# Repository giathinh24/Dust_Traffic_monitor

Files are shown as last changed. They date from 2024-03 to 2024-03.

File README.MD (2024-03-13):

# Development manual

## Arduino_code directory
The file in this directory is coded in Arduino programming language, but is compiled and loaded to an ARM-based STM32 BluePill development board.
Product link: *https://hshop.vn/products/kit-ra-chon-stm32f103c8t6*

In order to achive this, the developer must first install the **STM32F1 boards (Arduino-STM32)** board manager. Then, inside Arduino IDE, the developer must change the board from **Arduino** to the correct STM32 board (For Blue Pill development board, its STM32F103C8T6). This will allow the user to program the STM32 board with ease by utilizing Arduino high-level features, instead of having to code in bare C.

To add STM32F1 board manager:
-Open File > Preference
-Paste this link into your *Additional Boards Manager URLs*: http://dan.drown.org/stm32duino/package_STM32duino_index.json
-Click OK
-Go to Tools > Board > Board manager
-Install *STM32F1xx/GD32F1xx board* package

Now you have STM32F1xx boards manager. To use, go to Tools > Board > STM32F1 boards > Select the right model (Likely the *Fake STM32F103C8* one)

Now you can compile Arduino code into STM32 bytecode. But to upload, you cannot use USB cable like an Arduino, but you have to buy an ST-Link device. Product link: https://hshop.vn/products/mach-nap-st-link-v2

Now you can code, compile, and upload to an STM32 board, congrats.

## RaspberryPi_code directory
This directory hold the Python code to run on Raspbery Pi device.

The main file is **Run.py** where all the code are.
**Set_wifi.py** automatically write a .conf file that can connect the device to a new Wifi network. The user will be prompted with the SSID and password. Once completed, restart the device, the new Wifi connection will take effect. Be careful that this will log the device out of the old network, so if you rely on SSH to connect to the Raspberry Pi device, this operation will log you out.
**Set_parameters.py** is used to set 5 parameters that are used by the Run.py script. These are:
-video_cut_interval: How long should each video be cut before sending to the cloud (unit in seconds)
-frame_rate: Frame rate of the video. Maximum 30. Recommended 10. Higher FPS means larger files (unit in FPS)
-node_name: Name of the current device. Used to reference the device on cloud data base.
-data_buffer_time: How long should the dust data (csv files) be kept on the internal storage before clean up (unit in days)
-video_buffer_time: How many videos can buffer before clean up. The Run script will take time to upload a video to the cloud, so a video has to be buffered until the upload operation is done, before we can delete it. But the internal device storage is limited, so we cannot buffer too much. This param set how many files can exist in the buffer storage. Chosing 5 will means the device will only buffer the most recent 5 videos, once a new video is added, the oldest one will be deleted to make room. Please make this choice base on how big is the device's internal storage.

## PCB directory
**DustSensorMk1.sch** is the schematic file describe the logical connection between components
**DustSensorMk1.brd** is the board file describe the physical layout of the PCB

**CAMOutputs** directory store the CAM files that are used for PCB miling machines.
For machines used at VGU, use files in the GerberFiles directory.

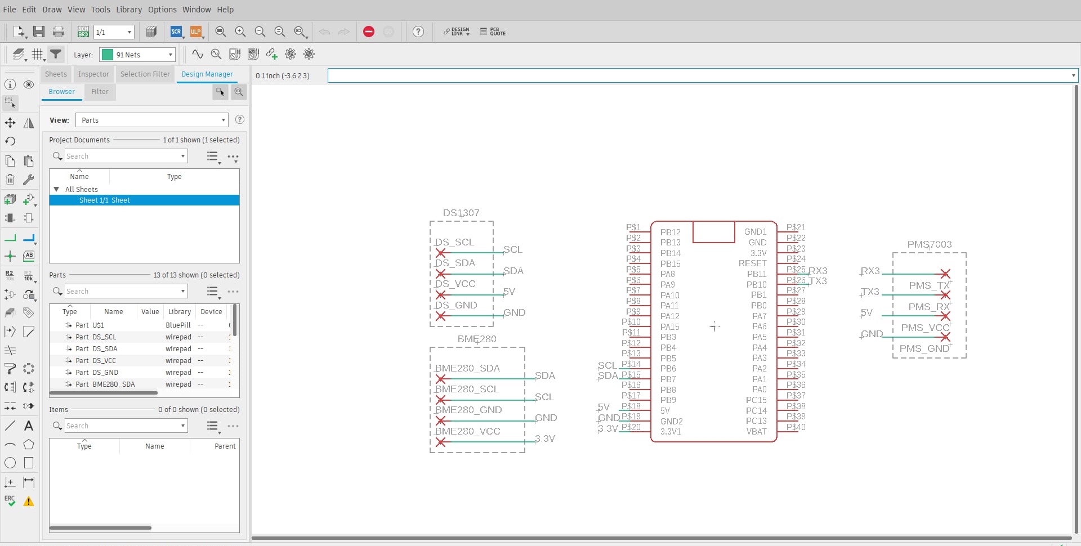
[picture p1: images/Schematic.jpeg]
Schematic

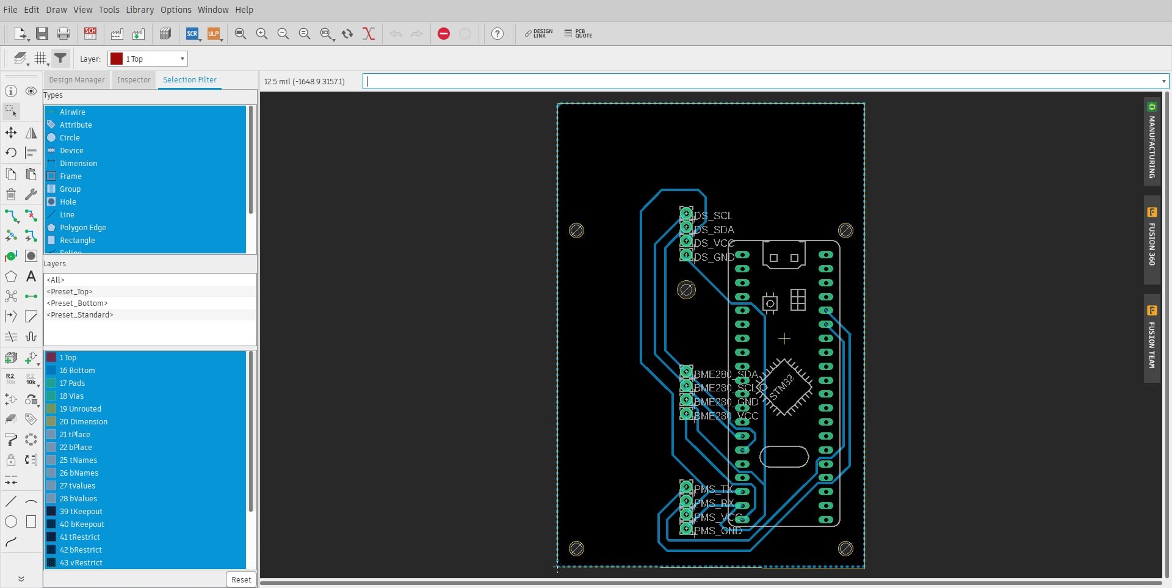
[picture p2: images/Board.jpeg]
Board layout


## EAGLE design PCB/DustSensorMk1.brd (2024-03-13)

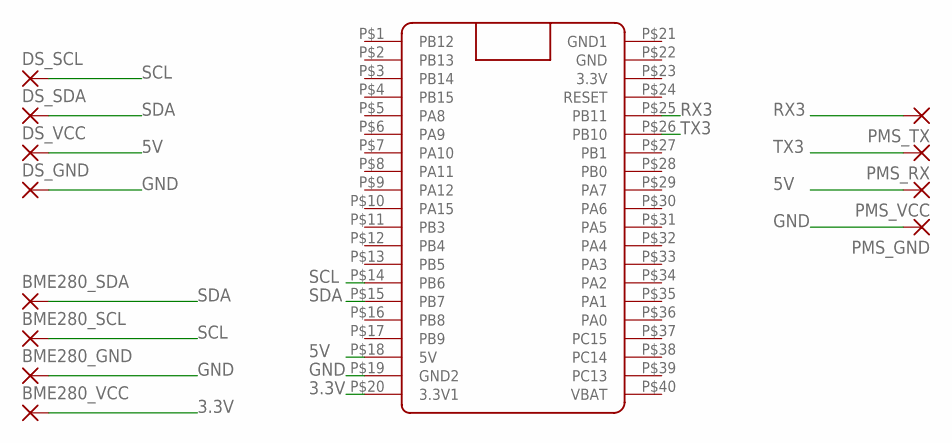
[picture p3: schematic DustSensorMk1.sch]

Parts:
BME280_GND, BME280_SCL, BME280_SDA, BME280_VCC: 2,15/1,0
DS_GND: 2,15/1,0
DS_SCL: 2,15/1,0
DS_SDA: 2,15/1,0
DS_VCC: 2,15/1,0
PMS_GND: 2,15/1,0
PMS_RX: 2,15/1,0
PMS_TX: 2,15/1,0
PMS_VCC: 2,15/1,0
U$1: BLUE_PILL

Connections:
3.3V: BME280_VCC.1, U$1.P$20 (3.3V1)
5V: DS_VCC.1, PMS_VCC.1, U$1.P$18 (5V)
GND: BME280_GND.1, DS_GND.1, PMS_GND.1, U$1.P$19 (GND2)
GND1: U$1.P$21 (GND1)
RX3: PMS_TX.1, U$1.P$25 (PB11)
SCL: BME280_SCL.1, DS_SCL.1, U$1.P$14 (PB6)
SDA: BME280_SDA.1, DS_SDA.1, U$1.P$15 (PB7)
TX3: PMS_RX.1, U$1.P$26 (PB10)

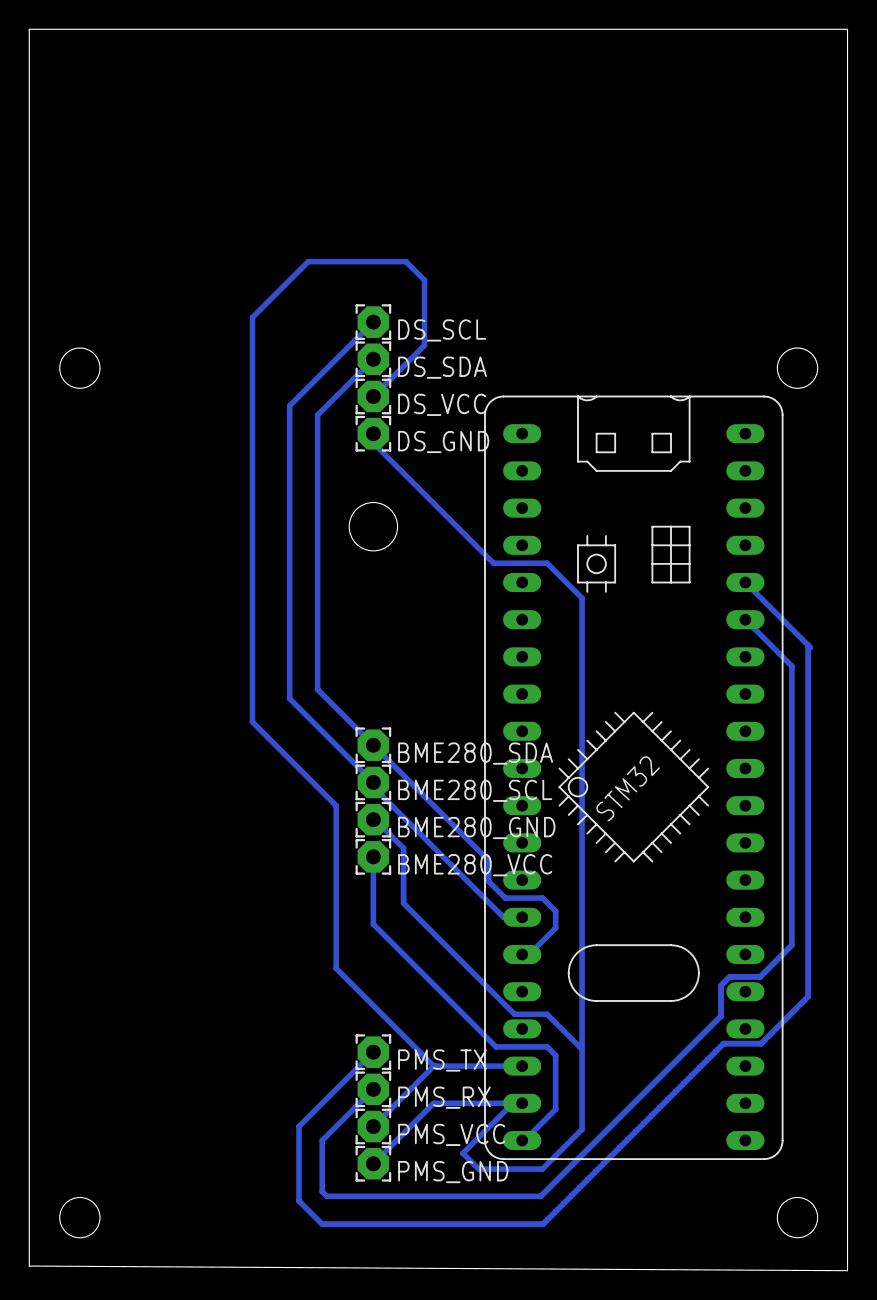
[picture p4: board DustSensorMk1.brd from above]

Board: 2 copper layers, 55.9 x 84.8 mm, 13 parts (0 on the bottom side), 7 nets.

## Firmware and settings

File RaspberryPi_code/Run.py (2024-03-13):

import serial, csv, datetime, time, math, os, sys, glob
from picamera import PiCamera
from azure.storage.blob import BlobServiceClient
from multiprocessing import Process
import RPi.GPIO as GPIO

# Getting parameters from parameters.txt
with open('parameters.txt', 'r') as file:
    lines = file.readlines()
    for line in lines:
        if (len(line)) == 0:
            lines.pop(line)
    video_cut_interval = int(lines[0].strip()) #seconds
    frame_rate = int(lines[1].strip()) #fps
    node_name = lines[2].strip()
    data_buffer_time = int(lines[3].strip()) #the days the datafiles will be kept on local storage
    video_buffer_time = int(lines[4].strip()) #the number of videos stored in the buffer before getting deleted

def upload_blob(container_name, file_path):
    try:
        connect_str = 'place_holder'
        blob_service_client = BlobServiceClient.from_connection_string(connect_str)

        # Create a container
        container_name = container_name
        local_file_name = file_path.split('/')[-1]
        upload_file_path = file_path
	try:
		blob_service_client.create_container(container_name)
	except:
		pass

        # Create a blob client using the local file name as the name for the blob
        blob_client = blob_service_client.get_blob_client(container=container_name, blob=local_file_name)

        print(datetime.datetime.now(), "Uploading to Azure Storage as blob:\t" + local_file_name)

        # Upload the created file
        with open(upload_file_path, "rb") as data:
            blob_client.upload_blob(data)
        print(datetime.datetime.now(), 'Finished uploading')

    except Exception as ex:
        print('Exception:')
        print(ex)

def serial_ports():
    """ Lists serial port names

        :raises EnvironmentError:
            On unsupported or unknown platforms
        :returns:
            A list of the serial ports available on the system
    """
    if sys.platform.startswith('win'):
        ports = ['COM%s' % (i + 1) for i in range(256)]
    elif sys.platform.startswith('linux') or sys.platform.startswith('cygwin'):
        # this excludes your current terminal "/dev/tty"
        ports = glob.glob('/dev/tty[A-Za-z]*')
    elif sys.platform.startswith('darwin'):
        ports = glob.glob('/dev/tty.*')
    else:
        raise EnvironmentError('Unsupported platform')

    result = []
    for port in ports:
        try:
            s = serial.Serial(port)
            s.close()
            result.append(port)
        except (OSError, serial.SerialException):
            pass
    return result

def delete_file(filepath):
    os.remove(filepath)
    print('Deleted', filepath)
    

ports = []
last_ports = []
GPIO.setmode(GPIO.BCM)
GPIO.setup(17, GPIO.OUT)
while True:
    ports = serial_ports()
    if len(last_ports) == 0:
        last_ports = serial_ports()
    com_port = list(set(ports).symmetric_difference(set(last_ports)))
    GPIO.output(17, GPIO.HIGH)
    if len(com_port) > 0:
        GPIO.output(17, GPIO.LOW)
        GPIO.cleanup()
        break
    print(ports, com_port)
    last_ports = ports

run_once = False
camera = PiCamera(framerate=frame_rate, sensor_mode = 5)

ser = serial.Serial(
    port=com_port[0],\
    baudrate=9600,\
    parity=serial.PARITY_NONE,\
    stopbits=serial.STOPBITS_ONE,\
    bytesize=serial.EIGHTBITS,\
        timeout=0)

print("connected to: " + ser.portstr)

epoch_time = int(round(time.time()))+25200
folder_name = '/home/pi/Raw_data'

# Create the raw data folder
try:
    os.mkdir(folder_name)
except:
    print('Folder', folder_name, 'is already created')

while True:
    epoch_time = int(round(time.time()))+25200 #offset for GMT+7
    video_filename = '{}_{}'.format(node_name, datetime.datetime.fromtimestamp(int(epoch_time-25200)).strftime( "%d%m%y_%H%M%S"))
    
    # Upload data file and delete old data file at the end of a day
    if (epoch_time)%86400==0:
        t = Process(target = upload_blob, args = ('node-'+node_name, data_filename,))
        t.start()
        t.join()
        temp_data_filename = '{}_{}'.format(node_name, datetime.datetime.fromtimestamp(int(math.floor((epoch_time-86400*data_buffer_time)/86400)*86400-25200)).strftime("%d%m%y"))+'.csv'
        delete_file_path = folder_name + '/' + temp_data_filename
        if os.path.isfile(delete_file_path):
            t = Process(target = delete_file, args = (delete_file_path,))
            t.start()
            t.join()
        files = os.listdir(folder_name)
        for file in files:
            if os.path.getctime(folder_name+'/'+file) <= int(math.floor((epoch_time-86400*data_buffer_time)/86400)*86400-25200) and file[-4:] == '.csv':
                t = Process(target = delete_file, args = (folder_name+'/'+file,))
                t.start()
                t.join()
    elif math.floor(epoch_time%video_cut_interval) != 0.0:
        data_filename = folder_name + '/{}_{}'.format(node_name, datetime.datetime.fromtimestamp(int(math.floor(epoch_time/86400)*86400-25200)).strftime("%d%m%y"))+'.csv'
    
    if math.floor(epoch_time%video_cut_interval) == 0.0 and not run_once:
        # Cute video
        try:
            camera.stop_recording()
        except:
            pass
        camera.start_recording(folder_name + '/{}.h264'.format(video_filename))
        
        # Upload to cloud storage
        run_once = True
        try:
            temp_video_filename = '{}_{}'.format(node_name, datetime.datetime.fromtimestamp(int((epoch_time-video_cut_interval*2)-25200)).strftime( "%d%m%y_%H%M%S"))+'.h264'
            path_arg = folder_name + '/' + temp_video_filename
            t = Process(target = upload_blob, args = ('node-'+node_name, path_arg,))
            t.start()
            t.join()
        except:
            pass
        
        #Remove old file
        temp_video_filename = '{}_{}'.format(node_name, datetime.datetime.fromtimestamp(int((epoch_time-video_cut_interval*video_buffer_time)-25200)).strftime( "%d%m%y_%H%M%S"))+'.h264'
        delete_file_path = folder_name + '/' + temp_video_filename
        if os.path.isfile(delete_file_path):
            t = Process(target = delete_file, args = (delete_file_path,))
            t.start()
            t.join()
        files = os.listdir(folder_name)
        for file in files:
            if os.path.getctime(folder_name+'/'+file) <= int((epoch_time-video_cut_interval*video_buffer_time)-25200) and file[-5:] == '.h264':
                t = Process(target = delete_file, args = (folder_name+'/'+file,))
                t.start()
                t.join()
    elif math.floor(epoch_time%video_cut_interval) != 0.0:
        run_once = False
    
    # Read data from serial
    line = ser.readline()
    
    # Create new datefile if file not exist
    try:
        with open(data_filename, 'r', newline = ''):
            pass
    except:
        with open(data_filename, 'w', newline = ''):
            pass
    
    # Read serial data and save to log file
    if len(line) > 0:
        data = line.decode('UTF-8').rstrip().split(',')
        data[0] = datetime.datetime.fromtimestamp(int(data[0])).strftime( "%Y-%m-%d %H:%M:%S") 
        print(data)
        with open(data_filename, 'a', newline = '') as file:
            writer = csv.writer(file)
            writer.writerow(data)

ser.close()

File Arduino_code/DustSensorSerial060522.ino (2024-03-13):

#include <BME280I2C.h>
#include <RtcDS1307.h>
#include <Wire.h>

// Operational variables
RtcDS1307<TwoWire> Rtc(Wire);
BME280I2C bme;
int last;
String data;
unsigned char pms[32]={0,};

// Setting variables
int update_interval = 10;

void setup() {
  pinMode(PC13, OUTPUT);
  digitalWrite(PC13, LOW);
  Serial.begin(115200);
  while(!Serial) {} // Wait
  
  //================ PMS7003 ===============
  Serial3.begin(9600);
  
  //================ BME280 ===============
  Wire.begin();
  while(!bme.begin())
  {
    Serial.println("Could not find BME280 sensor!");
    delay(1000);
  }

  //================ DS1307 ===============
  Rtc.Begin();
  //RtcDateTime compiled = RtcDateTime(__DATE__, __TIME__)-25200;
  //Rtc.SetDateTime(compiled); // Set clock time as system time
  Rtc.SetSquareWavePin(DS1307SquareWaveOut_Low);

  digitalWrite(PC13, HIGH);
}

void loop() {
  //================ PMS7003 ===============
  int checkSum = 0;
  if(Serial3.available()>=32){
    for(int j=0; j<32 ; j++){
      pms[j]=Serial3.read();
    }
  }

  //================ BME280 ===============
  float temp(NAN), hum(NAN), pres(NAN);
  BME280::TempUnit tempUnit(BME280::TempUnit_Celsius);
  BME280::PresUnit presUnit(BME280::PresUnit_Pa);
  bme.read(pres, temp, hum, tempUnit, presUnit);

  int current = Rtc.GetDateTime();
  //================ DS1307 ===============
  digitalWrite(PC13, HIGH);
  if (current%update_interval==0 && current!=last && current!=0){
    data = String(current+946684800) + ',' + String(temp) + ',' + String(hum) + ',' + String(pres);
    // 946684800 is the UNIX value at 00:00:00, Jan 1st 2000
    if (pms[0] == 66 && pms[1] == 77){
      data += ',' + String(pms[11]) + ',' + String(pms[13]) + ',' + String(pms[15]);
    }
    else {
      data += ",0,0,0";
    }
    Serial.println(data);
    digitalWrite(PC13, LOW);
  }
  last = current;
}
